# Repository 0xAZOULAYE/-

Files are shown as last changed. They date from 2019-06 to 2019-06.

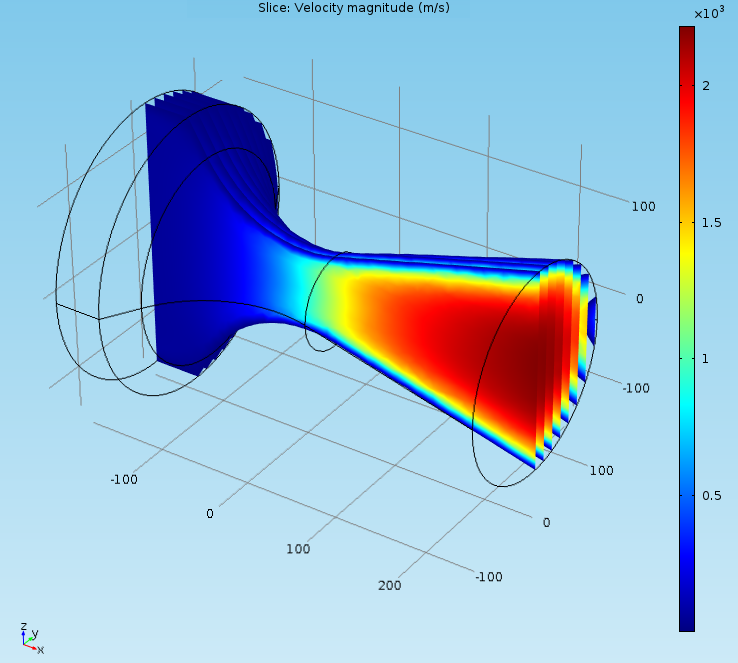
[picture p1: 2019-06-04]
Simulations/Nozzle 1 velocity.png

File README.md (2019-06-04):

(ⴰⵀⴱⵓ) ⴰⵜⴰⵔⴰⵎ ⴽⵍⴰⵙ ⴰⵙⵎⴰⴷ ⵏ ⵜⵓⵙⵏⴰ (ⴰⵏⵜ-50 ⴽⴳ)

- Payload capacity: 		  50 kg
- Minumum altitude:			  120 km
- Maximum accelertion:	  80 m/s2
- Micro-g time:				    4 minutes
- Flight frequency:			  1x per day
- Propulsion:				      Double Base Solid
	Fuel:					          Nitrocellulose + Nitroglycerine
	Oxidizer:				        XXX
	Stabilizer:				      Di-Nitro-diphenylamine
	Plasticizer:			      Di-ethyl-phthalate

	Composition:			      1. NC:		53.0	% 
							            2. NG:		40.5	%
							            3. DEP:		4.0		%
							            4. 2NDPA:	2.5		%

- Stages: 					      1.0

- Control surfaces:
	1. Booster:
		- Spin Stabilization

- Capsule design:
	1. Exposed to the vacuum of space

- Pressurized capsule conditions:
	1. Temperature:				293		K
	2. Noise:					    60 		dB
	3. Humidity:				  50% 	RH
	4. Pressure:				  84		kPa

- Maximum dimensions:
	Diameter: 					  0.2 	meters
	Length: 					    12.0	meters

- Vibrations:
	1. Lateral accelerations: 	+/- 20 m/s2
	2. Frequency range:			    1Hz to 100Hz
	3. Frequency (Hz)		        Acceleration (m/s2)
		5							  5
		20							8
		30							8
		30							6
		75							6
		85							9
		100							9

- Capsule dimensions:
	1. Diameter:				0.3 meters
	2. Height:					2 meters

- Recovery methods:
	1. Booster:					Parachute + grid fins
	2. Capsule:					Parachute + CGT

- Telemetry:
	1. Channels:				11x
	2. Sensors:
								Temperature
								Humidity
								Accelerations/Vibrations
								GPS
								UHF
								Radar altimiter
								4x External Stationary Cameras
								4x Internal Payload Cameras
								2x External Stage Cameras

	3. Power: 					12/24V DC

- Materials:
	1. Airframe: 		6068-T6
	2. Motor casing: 	316L
	3. Nozzle:			graphite
	4. Fairing:			PMMA
	5. Parachute:		Nylon
	6. Primer:			Lead-azide
	7. Secondary:		RDX

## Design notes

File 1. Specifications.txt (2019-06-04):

- Goals:
	1. Ability to launch and recover delicate payloads
	2. Reusability
	3. Quick turnaround times
	4. More control
	5. Factor of 10x cheaper compared to Spaceloft XL

- Payload capacity: 		50 kg
- Minumum altitude:			120 km
- Maximum accelertion:		80 m/s2
- Micro-g time:				4 minutes
- Flight frequency:			1x per day
- Propulsion:				Double Base Solid
	Fuel:					Nitrocellulose + Nitroglycerine
	Oxidizer:				XXX
	Stabilizer:				Di-Nitro-diphenylamine
	Plasticizer:			Di-ethyl-phthalate

	Composition:			1. NC:		53.0	% 
							2. NG:		40.5	%
							3. DEP:		4.0		%
							4. 2NDPA:	2.5		%

- Price:					1000 USD/kg

- Stages: 					3.0
	First 3 stages: 		Booster

- Control surfaces:
	1. Booster:
		- LITVC

	2. Booster:
		- Spin Stabilization

	3. Booster:
		- Spin Stabilization

- Capsule design:
	1. Exposed to the vacuum of space

- Pressurized capsule conditions:
	1. Temperature:				293		K
	2. Noise:					60 		dB
	3. Humidity:				50% 	RH
	4. Pressure:				84		kPa

- Maximum dimensions:
	Diameter: 					0.2 	meters
	Length: 					12.0	meters

- Vibrations:
	1. Lateral accelerations: 	+/- 20 m/s2
	2. Frequency range:			1Hz to 100Hz
	3. Frequency (Hz)		Acceleration (m/s2)
		5							5
		20							8
		30							8
		30							6
		75							6
		85							9
		100							9

- Capsule dimensions:
	1. Diameter:				0.3 meters
	2. Height:					2 meters

- Recovery methods:
	1. Booster:					Parachute + grid fins
	2. Capsule:					Parachute + CGT

- Telemetry:
	1. Channels:				11x
	2. Sensors:
								Temperature
								Humidity
								Accelerations/Vibrations
								GPS
								UHF
								Radar altimiter
								4x External Stationary Cameras
								4x Internal Payload Cameras
								2x External Stage Cameras

	3. Power: 					12/24V DC

- Materials:
	1. Airframe: 		6068-T6
	2. Motor casing: 	316L
	3. Nozzle:			graphite
	4. Fairing:			PMMA
	5. Parachute:		Nylon
	6. Primer:			Lead-azide
	7. Secondary:		RDX

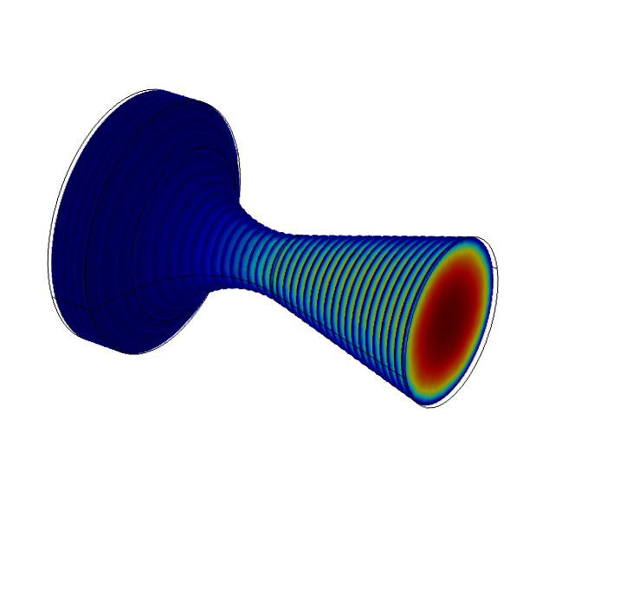
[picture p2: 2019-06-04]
Simulations/Nozzle 2 velocity.png

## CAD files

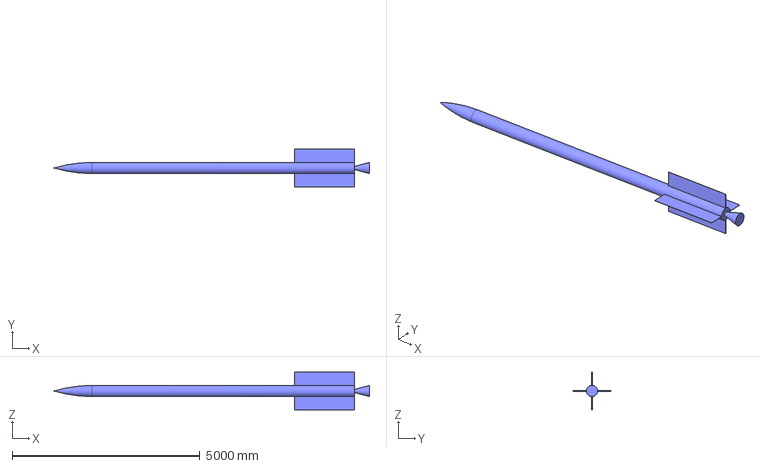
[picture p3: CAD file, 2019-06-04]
Simulations/Body5.FCStd
8393.7 x 1000.0 x 1000.0 mm

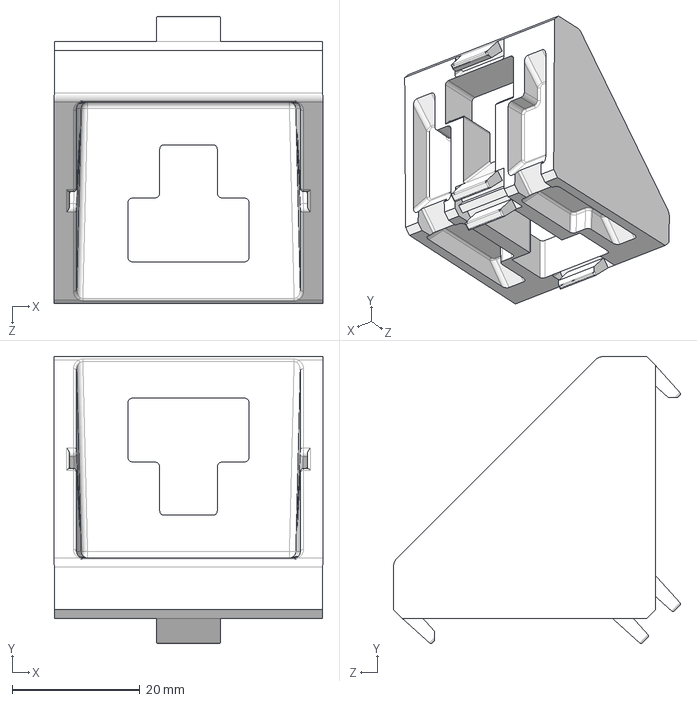
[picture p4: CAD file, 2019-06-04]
Vendor Components/Bracket_45_B-Type_slot_10.STEP
42.0 x 44.9 x 44.9 mm

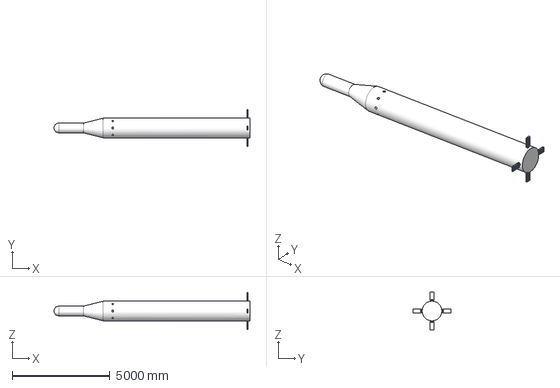
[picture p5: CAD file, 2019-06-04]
Simulations/CFD_body_model_step.stp
10000.0 x 1900.0 x 1900.0 mm

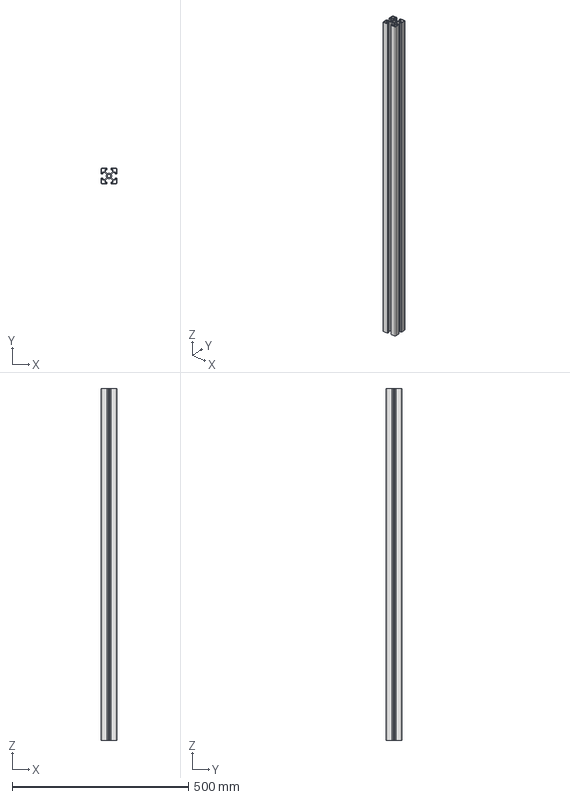
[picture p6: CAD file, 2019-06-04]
Vendor Components/Motedis Profile 45x45L B-Type slot 10.stp
45.0 x 45.0 x 1000.0 mm

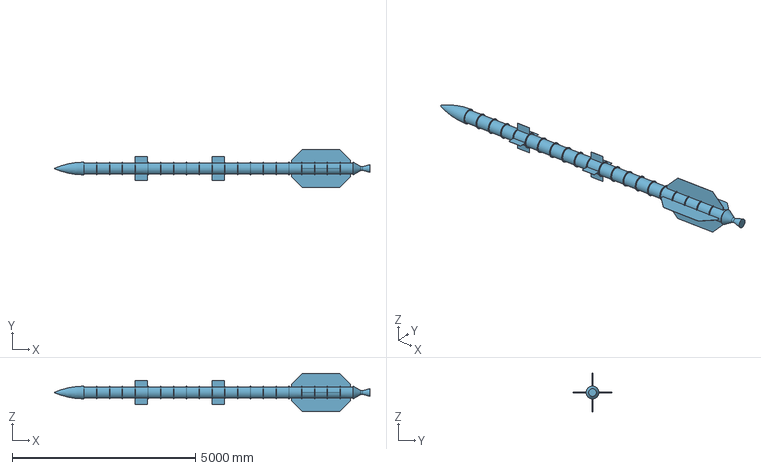
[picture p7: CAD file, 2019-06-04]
Simulations/Body3.FCStd
8631.4 x 1050.0 x 1050.0 mm

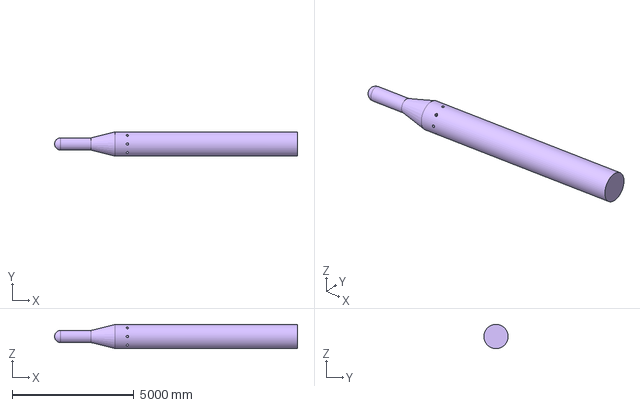
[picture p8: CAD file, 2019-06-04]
Simulations/CFD_body_model_V2.FCStd
10000.0 x 1000.0 x 1000.0 mm

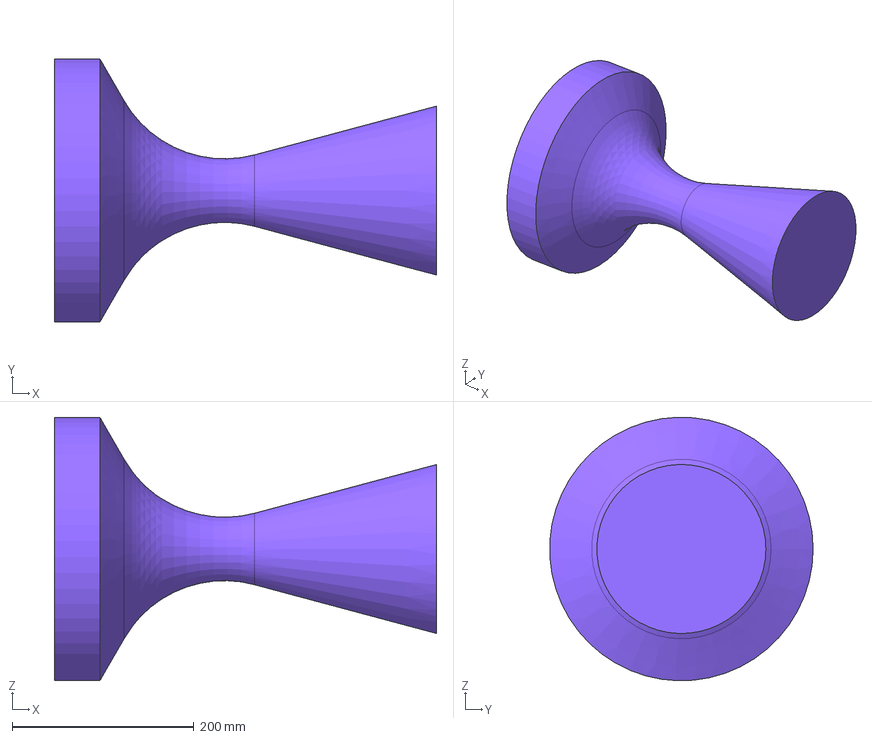
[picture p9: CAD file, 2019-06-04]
Simulations/Nozzle_2.step
420.4 x 289.7 x 289.9 mm

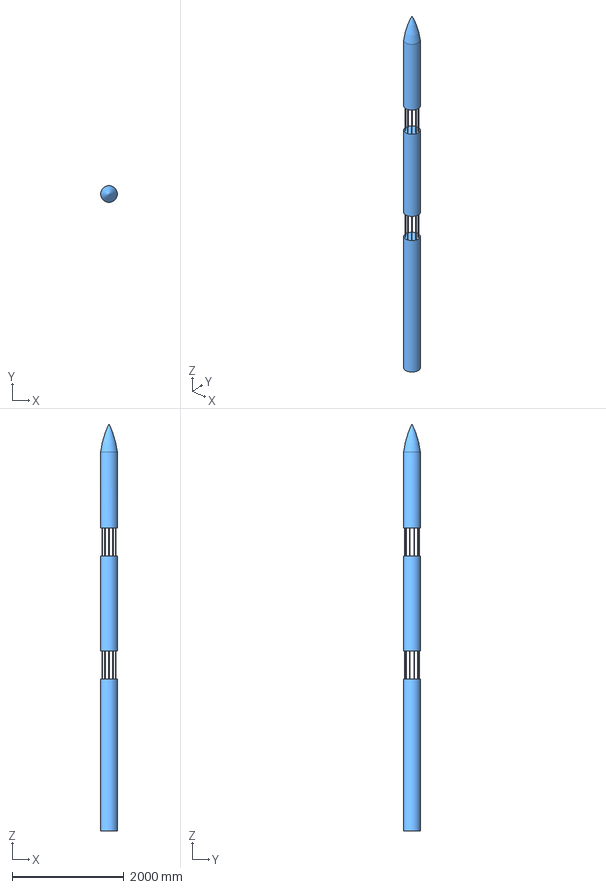
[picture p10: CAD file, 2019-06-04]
Simulations/Body4.FCStd
299.9 x 299.9 x 7280.0 mm

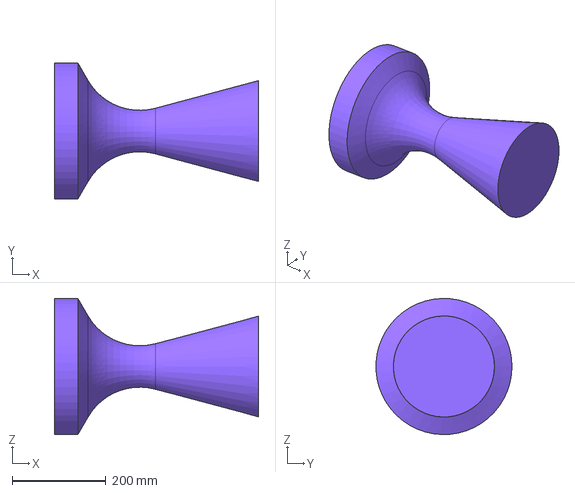
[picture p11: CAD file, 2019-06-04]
Simulations/Nozzle_1.step
434.6 x 289.7 x 289.9 mm

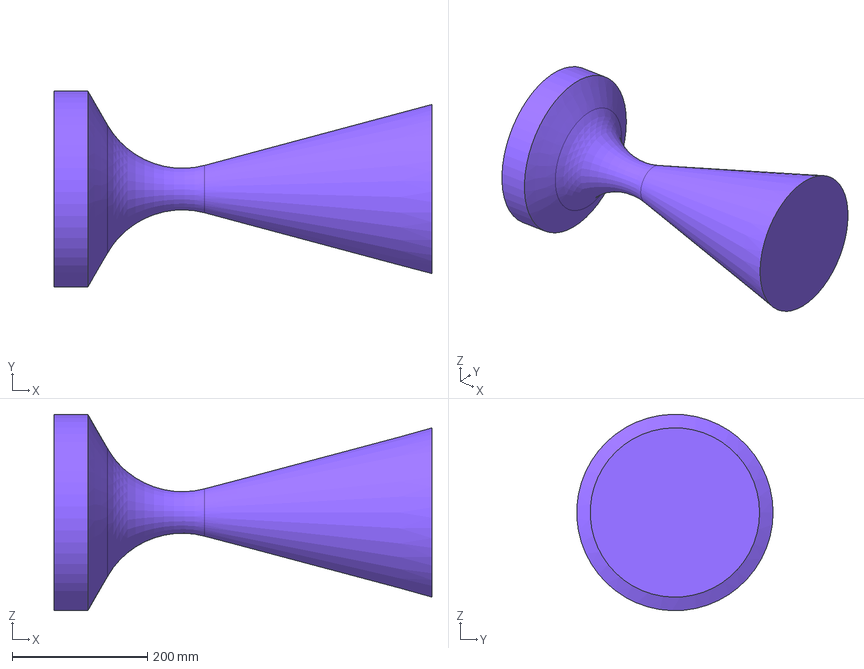
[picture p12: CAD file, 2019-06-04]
Simulations/Nozzle_3.step
558.1 x 289.7 x 289.9 mm

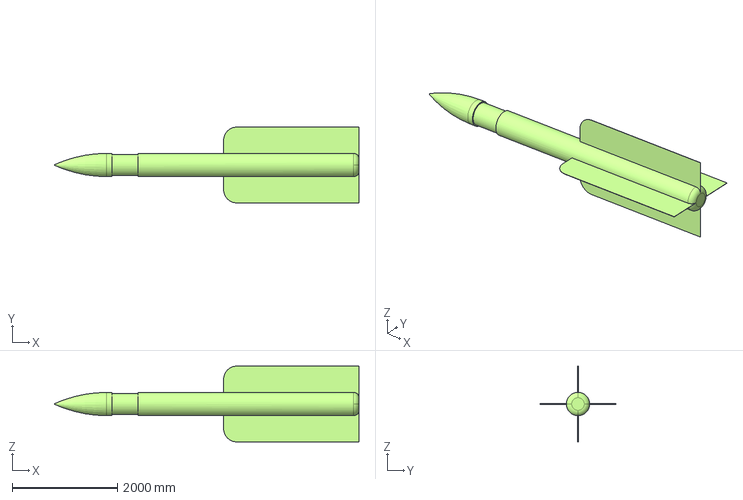
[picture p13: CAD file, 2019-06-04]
Simulations/Body6.FCStd
5800.0 x 1442.0 x 1442.0 mm

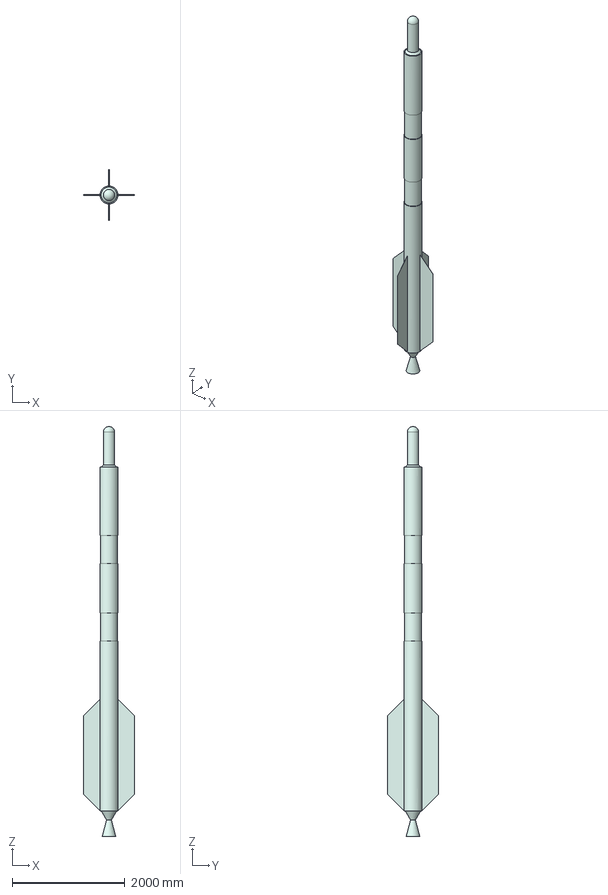
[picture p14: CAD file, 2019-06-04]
Simulations/Body2.step
900.0 x 900.0 x 7285.0 mm

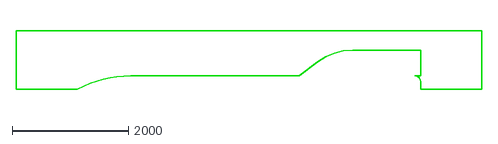
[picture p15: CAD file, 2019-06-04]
Simulations/Body_profile.dxf
8000.0 x 1000.0

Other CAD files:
Simulations/BodyProfile5.iges
Simulations/CFD_body_model_V2_FLAPS.FCStd
Simulations/CFD_body_model.step
Assemblies/AMDO.010-MA.001.prt
Assemblies/AMDO.010-MA.002.prt
Assemblies/AMDO.010-MA.003.prt
Assemblies/AMDO.010-MA.004.prt
Assemblies/AMDO.010-MA.005.prt
Assemblies/AMDO.010-MA.008.prt
Assemblies/AMDO.010-MA.010.prt
Assemblies/AMDO.010-MA.011.prt
Assemblies/AMDO.010-MA.012.prt
Assemblies/AMDO.010-MA.013.prt
Assemblies/AMDO.010-MA.014.prt
Assemblies/AMDO.010-MA.015.prt
Assemblies/AMDO.010-MA.016.prt
Assemblies/AMDO.010-MA.prt
Simulations/BODY3.iges
Simulations/BODY4.iges
Simulations/BODY5.iges
Simulations/BODY6.iges
Simulations/Body2.FCStd
Simulations/CFD_body_model.FCStd
Simulations/CFD_body_model_step.prt
Simulations/Nozzle_1.FCStd
Simulations/Nozzle_2.FCStd
Simulations/Nozzle_3.FCStd
Vendor Components/Bracket_45_B-Type_slot_10_step.prt
Vendor Components/VC.010-MA.002.prt
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

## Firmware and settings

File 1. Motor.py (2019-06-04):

"""
//This script is meant to dimension the internal grain and nozzle of the solid rocket motor
//The following aspects are calculated:
    // - Grain core diameter
    // - Grain outer diameter
    // - Grain length
    // - Grain shape
    // - Grain burn profile
    // - Nozzle entry diameter
    // - Nozzle throat diameter
    // - Nozzle exit diameter
    // - Nozzle throat radius
    // - Nozzle length

    	Composition:		1. NC:		53.0	% 
							2. NG:		40.5	%
							3. DEP:		4.0		%
							4. 2NDPA:	2.5		%
"""

import math
import matplotlib.pyplot as plt
import numpy as np
from decimal import *

getcontext().prec = 7

m_payload = 50.0
n_stages = 1.0

frac_payload = 10.0/100.0
frac_structural = 20.0/100.0
frac_propellant = 1.0 - frac_payload - frac_structural


m_total = 620.0 #1/frac_payload * m_payload
m_propellant = 370.0 #m_total * frac_propellant
m_structural = 200.0 #m_total * frac_structural

m_capsule = m_payload * (1 + frac_structural)
m_stages = m_total - m_capsule

m_individual_stage_1 = m_stages - m_capsule
m_individual_stage_structural_1 = m_individual_stage_1

#m_individual_stage_2 = m_stages/16.0*4.0
#m_individual_stage_structural_2 = m_individual_stage_2*frac_structural

#m_individual_stage_3 = m_stages/16.0*1.0
#m_individual_stage_structural_3 = m_individual_stage_3*frac_structural

Cd_z = 0.03
Cd_r = 1.0

D_body = 442.0/1000.0
D_capsule = 442.0/1000.0


def main():

    rho_NC = 770.0
    rho_NG = 1600.0
    rho_DEP = 1120.0
    rho_2NDPA = 1300.0

    rho_grain_NG_NC = rho_NC*0.53 + rho_NG*0.405 + rho_DEP*0.04 + rho_2NDPA*0.025

    print("Rho grain: {0}".format(rho_grain_NG_NC))

    T_flame = 2720.0                #K

    I_sp = 215.0
    g0 = 9.81

    F_thrust_1 = 50000.0             #N
    #F_thrust_2 = 22000.0             #N
    #F_thrust_3 = 17000.0             #N

    t_thrust = 24.0                 #seconds

    D_max = 452.0/1000.0             #m
    L_max = 4.0                     #m
    m_max = 397.0                   #kg

    motor_OD = D_max
    motor_ID = 40.0/1000.0

    #Determine the motor operation conditions
    P_max = 4000000.0

    P_max_1 = 3700000.0
    #P_max_2 = 2500000.0
    #P_max_3 = 1900000.0

    #NG-NC propellant
    n_motor = 0.64
    a_motor = (2.3*10**-3)/((1.0*10.0**6)**n_motor)

    H_exp_min = 3.47*10**6 #J/kg
    H_exp_max = 4.59*10**6 #J/kg
    

    r_motor_1 = burn_rate(P_max_1, a_motor, n_motor)
    #r_motor_2 = burn_rate(P_max_2, a_motor, n_motor)
    #r_motor_3 = burn_rate(P_max_3, a_motor, n_motor)


    #Grain geometry = rod and tube
    R_rod_support = 5.0e-3
    W_tube = 45.0e-3
    R_rod = 88.0e-3 #Starting diameter rod
    R_tube = R_rod + W_tube #Starting diameter tube
    
    #n_stages, t_stage = number_of_stages(r_motor, R_rod, t_thrust, R_rod_support)

    n_stages, t_stage_1 = number_of_stages(r_motor_1, R_rod, t_thrust, R_rod_support)
    #n_stages, t_stage_2 = number_of_stages(r_motor_2, R_rod, t_thrust, R_rod_support)
    #n_stages, t_stage_3 = number_of_stages(r_motor_3, R_rod, t_thrust, R_rod_support)



    motor_OD_final = (R_tube + r_motor_1*t_stage_1) * 2.0

    m_flow_1 = (F_thrust_1/(I_sp*g0))
    #m_flow_2 = (F_thrust_2/(I_sp*g0))
    #m_flow_3 = (F_thrust_3/(I_sp*g0))

    m_flow_total = 0.0

    #Compute the initial grain surface area
    A_burn_1 = m_flow_1/(rho_grain_NG_NC*r_motor_1)
    #A_burn_2 = m_flow_2/(rho_grain_NG_NC*r_motor_2)
    #A_burn_3 = m_flow_3/(rho_grain_NG_NC*r_motor_3)

    #Determine the length of the grain
    L_grain_1 = A_burn_1/(2.0*math.pi*R_rod + 2.0*math.pi*R_tube)
    #L_grain_2 = A_burn_2/(2.0*math.pi*R_rod + 2.0*math.pi*R_tube)
    #L_grain_3 = A_burn_3/(2.0*math.pi*R_rod + 2.0*math.pi*R_tube)

    erosive_factor_1 = [0.0]
    #erosive_factor_2 = [0.0]
    #erosive_factor_3 = [0.0]

    L_grain_total = L_grain_1 #+ L_grain_2 + L_grain_3
    V_grain_total = (((math.pi * R_rod**2.0) - (math.pi * R_rod_support**2.0)) + ((math.pi * (motor_OD_final/2.0)**2.0) - (math.pi * R_tube**2.0))) * (L_grain_1)
    m_grain_total = V_grain_total*rho_grain_NG_NC

    #Plot the massflow rate over the thrust period
    P_exit_1 = 101250.0
    #P_exit_2 = 80000.0
    #P_exit_3 = 48200.0

    n_steps = 1000.0
    dt = 1.0/n_steps
    t_burn = 0.0
    timestamp_1 = [0.0]
    #timestamp_2 = [0.0]
    #timestamp_3 = [0.0]

    n_counter = 1.0
    
    A_burn_intermediate_1 = A_burn_1
    #A_burn_intermediate_2 = A_burn_2
    #A_burn_intermediate_3 = A_burn_3

    m_flow_intermediate_1 = [0.0]
    #m_flow_intermediate_2 = [0.0]
    #m_flow_intermediate_3 = [0.0]

    F_thrust_intermediate_1 = [0.0]
    #F_thrust_intermediate_2 = [0.0]
    #F_thrust_intermediate_3 = [0.0]

    P_c_intermediate_1 = [0.0]
    #P_c_intermediate_2 = [0.0]
    #P_c_intermediate_3 = [0.0]

    r_motor_intermediate_1 = [0.0]
    #r_motor_intermediate_2 = [0.0]
    #r_motor_intermediate_3 = [0.0]

    M_exhaust_1 = [0.0]
    #M_exhaust_2 = [0.0]
    #M_exhaust_3 = [0.0]

    rod_stage_1 = R_rod
    #rod_stage_2 = R_rod
    #rod_stage_3 = R_rod

    Isp_stage_1 = [0.0]
    #Isp_stage_2 = [0.0]
    #Isp_stage_3 = [0.0]

    R_gas_universal = 8.31445 #J/k.mol
    M_gas = (0.397*28.01 + 0.124*44.01 + 0.115*2.01 + 0.238*18.01 + 0.124*28.0134 + 0.1/100.0*17.001 + 0.2/100.0*1.007)/1000.0 #(R_gas_universal * T_flame * rho_grain_NG_NC)/P_max
    R_gas_specific = R_gas_universal/M_gas

    k = 1.2
    Cp = R_gas_specific/(1.0 - 1.0/k)

    A_throat_1 = m_flow_1/(((((2/(k+1))**((k+1)/(k-1)))**0.5) / ((k*R_gas_specific*T_flame)**0.5))*P_max_1*k)*0.65
    D_throat_1 = ((A_throat_1/math.pi)**0.5)*2.0

    #Define the exit diameter
    A_exit_1 = A_throat_1 * (((k* (2.0/(k+1.0) )**((k+1)/(k-1)))**0.5) / ((P_exit_1/P_max_1)**(1.0/k) * (((2.0*k) / (k-1)) * (1.0 - (P_exit_1/P_max_1) ** ((k-1)/k)) )**0.5))*4.0
    D_exit_1 = ((A_exit_1/math.pi)**0.5)*2.0

    print("Motor 1 throat diameter: {0} mm".format(D_throat_1*1000.0))
    print("Motor 1 exit diameter: {0} mm".format(D_exit_1*1000.0))
    
    """
    A_throat_2 = (m_flow_2/(((((2/(k+1))**((k+1)/(k-1)))**0.5) / ((k*R_gas_specific*T_flame)**0.5))*P_max_2*k))
    D_throat_2 = ((A_throat_2/math.pi)**0.5)*2.0

    #Define the exit diameter
    A_exit_2 = A_exit_1 #A_throat_2 * (((k* (2.0/(k+1.0) )**((k+1)/(k-1)))**0.5) / ((P_exit_2/P_max_2)**(1.0/k) * (((2.0*k) / (k-1)) * (1.0 - (P_exit_2/P_max_2) ** ((k-1)/k)) )**0.5))
    D_exit_2 = ((A_exit_2/math.pi)**0.5)*2.0

    print("Motor 2 throat diameter: {0} mm".format(D_throat_2*1000.0))
    print("Motor 2 exit diameter: {0} mm".format(D_exit_2*1000.0))

    A_throat_3 = (m_flow_3/(((((2/(k+1))**((k+1)/(k-1)))**0.5) / ((k*R_gas_specific*T_flame)**0.5))*P_max_3*k))
    D_throat_3 = ((A_throat_3/math.pi)**0.5)*2.0

    #Define the exit diameter
    A_exit_3 = A_exit_1 #A_throat_3 * (((k* (2.0/(k+1.0) )**((k+1)/(k-1)))**0.5) / ((P_exit_3/P_max_3)**(1.0/k) * (((2.0*k) / (k-1)) * (1.0 - (P_exit_3/P_max_3) ** ((k-1)/k)) )**0.5))
    D_exit_3 = ((A_exit_3/math.pi)**0.5)*2.0
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
